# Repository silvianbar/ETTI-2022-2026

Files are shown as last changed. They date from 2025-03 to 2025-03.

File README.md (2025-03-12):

# Amplificator de Tensiune (Joasă Frecvență)
### Descriere
Acest proiect constă în proiectarea și realizarea unui amplificator de tensiune de joasă frecvență, conform specificațiilor definite. Scopul amplificatorului este de a crește amplitudinea semnalelor electrice de joasă frecvență (20 Hz - 20 kHz) menținând integritatea semnalului original.

### Specificații Tehnice

- Semnal de intrare: 360mV
- Sarcina la ieșire: 600 Ω
- Rezistența de intrare (Ri): >150 kΩ
- Rezistența de ieșire (Ro): < 0.6Ω
- Amplificare in tensiune (Av): 10
- Temperaturi de funcționare: -20°C - 120°C
- Indicator LED pentru prezența tensiunii de alimentare

### Principiul de Funcționare
Amplificatorul funcționează conform principiilor circuitelor electrice, utilizând tranzistoare pentru amplificarea semnalului. Formula fundamentală este:

`Av = Uout / Uin`

unde:

- Av este câștigul de tensiune
- Uout este tensiunea de ieșire
- Uin este tensiunea de intrare
- Pentru stabilitate, este utilizată reacția negativă, care menține amplificarea constantă.

### Componente Principale

- Etajul diferențial de intrare - folosește tranzistoare Q1 și Q2 (QBC846B)
- Sursa de curent constant - tranzistor Q5 reglează curentul circuitului
- Etajul de amplificare de tensiune - include tranzistoarele Q6, Q7 și rezistențe de stabilizare
- Etajul de ieșire - configurat push-pull cu tranzistoare Q12 și Q13 (QBC807-25)
- Indicator LED - pentru semnalizarea prezenței tensiunii de alimentare
- Schema Bloc
(Schema bloc a amplificatorului poate fi adăugată sub formă de imagine)

### Instalare și Utilizare

1. Descărcați fișierele proiectului din acest repository.
2. Construiți circuitul conform schemei electrice.
3. Alimentați circuitul cu tensiunea corespunzătoare.
4. Testați funcționarea și verificați amplificarea tensiunii de ieșire.

### Autori
Student: Baroiu Silvian
Coordonatori: Draghici Florin, Pantazica Mihaela
Licență
Acest proiect este realizat în cadrul Universității Naționale de Știință și Tehnologie Politehnica București, Facultatea de Electronică, Telecomunicații și Tehnologia Informației, 2024.

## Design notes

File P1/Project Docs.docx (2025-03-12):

Universitatea Națională de Știință și Tehnologie POLITEHNICA București Facultatea de Electronică ,Telecomunicații și Tehnologia Informației

Referat

Proiect 1 - Dispozitive și circuite electronice

Tema:

Amplificator de tensiune (joasă frecvență)

Baroiu Silvian

Grupa : 431D

Date initiale de proiectare: N = 6

Să se proiecteze și realizeze un amplificator de tensiune (joasă frecvență) având următoarele caracteristici:

- Semnal de intrare, ui in gama: 360 [mV];
- Sarcina la ieșire, RL: 60 [Ω];
- Rezistența de intrare Ri >150 [kΩ];
- Rezistența de ieșire Ro < 0,6 [Ω];
- Amplificare în tensiune, Av: 10;
- Tensiunea la ieşire 3,6 V.
- Domeniul temperaturilor de funcționare: 0-70C (verificabil prin testare în temperatură);
- Semnalizarea prezenței tensiunilor de alimentare cu diodă de tip LED.

Introducere:

Amplificatorul de tensiune este un circuit care are rolul de a furniza la iesirea sa o tensiune proportionala cu cea de la intrare. Relatia de baza este:

(1)

unde :

- Uies= este tensiunea de la iesirea amplificatorului;
- Uin= este tensiunea de la intrarea amplificatorului;
- Av= amplificarea amplificatorului , marime adimensionala , mai mare , in modul decat 1. Daca Av>0 , atunci amplificatorul se numeste neinversor , iar daca Av<0 , amplificatorul se numeste inversor.

Formula (1) este dificil de respectat cu exactitate în practică, deoarece, în special, mărimea Av nu este constantă și depinde de mai mulți factori, inclusiv de Uin. Acest lucru determină ca amplificatoarele de precizie să fie proiectate cu o reacție negativă puternică. Pentru a realiza acest lucru, se utilizează un amplificator cu două intrări: una inversoare și una neinversoare, formând astfel un amplificator diferențial. Acest tip de amplificator amplifică diferența dintre tensiunile aplicate la intrările neinversoare și inversoare.

La intrarea neinversoare se aplică semnalul, iar la cea inversoare o fracțiune din tensiunea de la ieșirea amplificatorului, cu f < 1kHz.

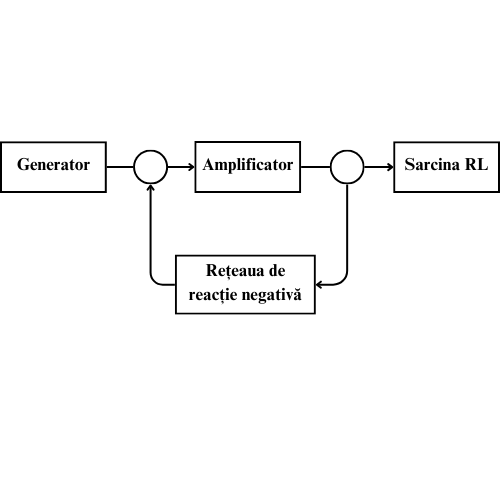
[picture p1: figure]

Schema bloc a amplificatorului de tensiune:

Schema electică a amplificatorului:

Pentru acest amplificator, am utilizat o reacție Serie-Paralel, caracterizată de o amplificare mare în buclă deschisă, o impedanță de intrare ridicată și o impedanță de ieșire foarte scăzută, fiind realizat cu ajutorul tranzistoarelor bipolare. Structura adoptată a fost următoarea:

Circuitul de intrare format din Q1 și Q2 este un amplificator diferențial realizat cu tranzistoare bipolare de joasă frecvență și putere redusă. Curentul prin cele două tranzistoare PNP este stabilit de sursa de curent Q3. Acest tranzistor furnizează un curent simetric de aproximativ 0,6 mA fiecărui tranzistor din amplificatorul diferențial.

Etajul diferențial este urmat de o oglindă de curent simetrică. Tranzistoarele Q7 și Q8, de putere redusă, sunt echipate fiecare cu o rezistență de 1 kΩ în emitor. Scopul acestei oglinzi de curent este de a asigura un curent identic la ieșire, contribuind astfel la obținerea unei liniarități ridicate și a unor distorsiuni minime.

Etajul diferențial este urmat de un amplificator în tensiune, realizat cu tranzistorul Q6, un tranzistor NPN de mică putere. Între baza și colectorul tranzistorului Q6 este conectat un condensator de compensare (efectul Miller), care are rolul de a ajusta banda de frecvență. Alimentarea tranzistorului Q6 este asigurată de tranzistorul Q7.

Etajul final funcționează în clasa B și este alcătuit din două tranzistoare care formează un tranzistor Darlington complementar. Acestea sunt compuse din perechile de tranzistoare Q10, Q11 și Q8, Q10.

Diodelor LED le este asigurată funcționarea în conducție prin intermediul unei rezistențe de 880 Ω conectată în serie. Diodelor cu joncțiune p-n li se permite de asemenea să funcționeze în regim de conducție, având următoarele valori ale curentului: diodele D1 și D2 conduc un curent de aproximativ 1,5 mA, diodele D3 și D4 circa 300 μA, iar diodele D5 și D6 aproximativ 13,4 mA.

Rețeaua de reacție negativă este formată din tranzistorul Q2 și rezistențele R9 și R10. Amplificarea în buclă închisă a montajului este dată de formula A=(R1+R2)/R1 . Pentru a respecta cerințele de proiectare, am ales raportul rezistențelor R1 și R2 să fie aproximativ 9.

Schema Electrică a Circuitului:

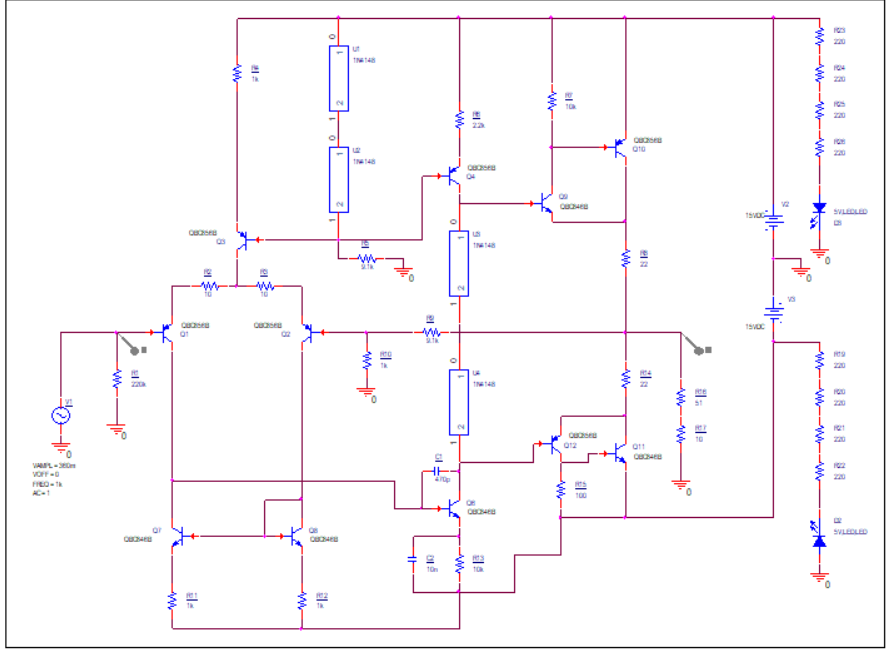
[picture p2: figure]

PSF:

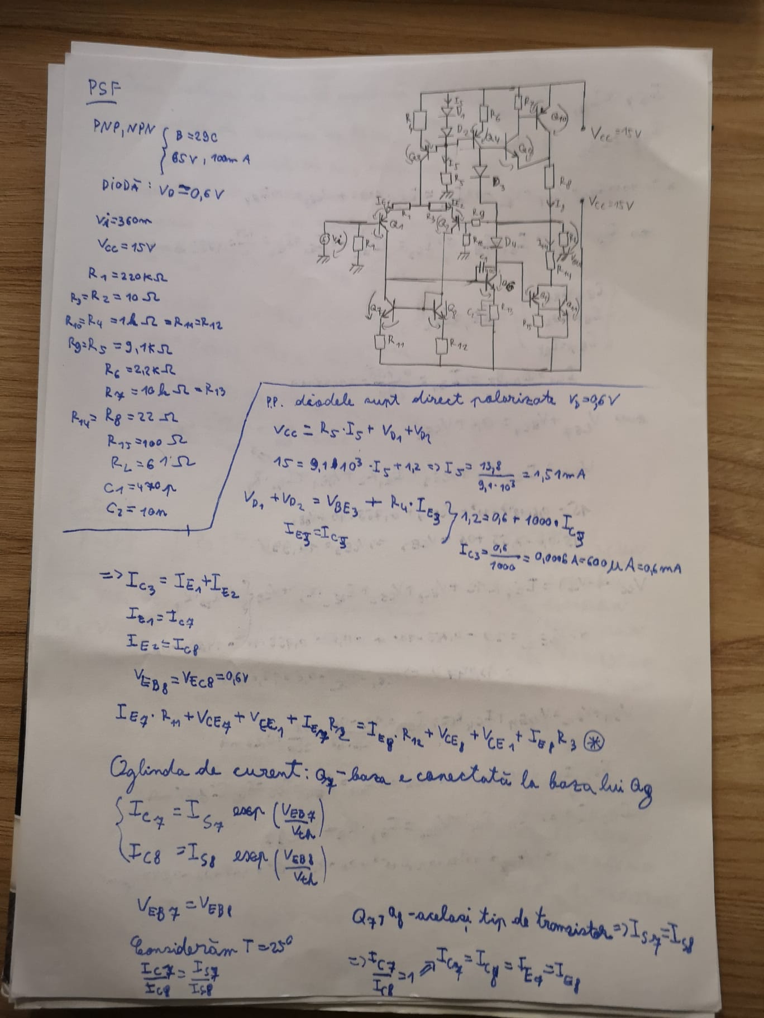
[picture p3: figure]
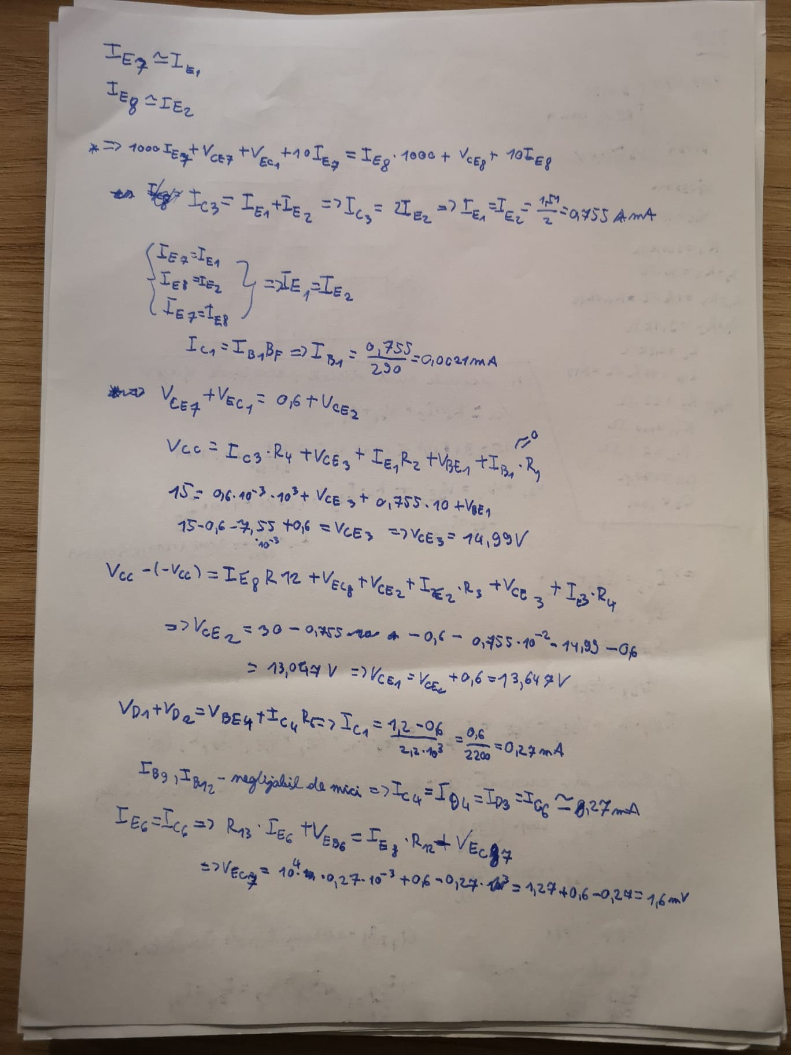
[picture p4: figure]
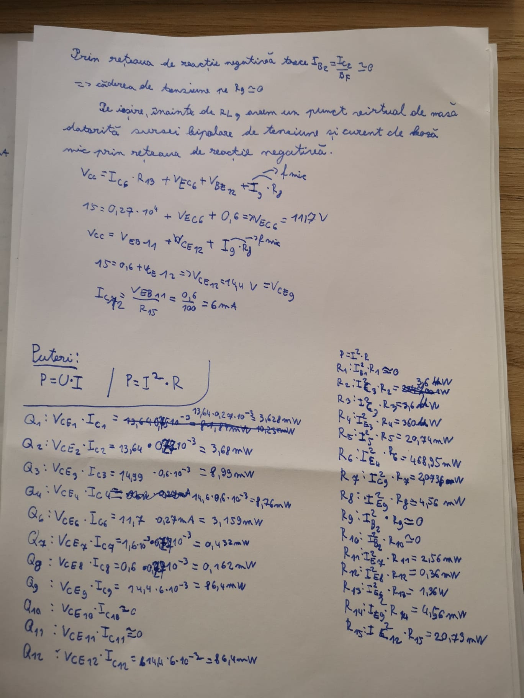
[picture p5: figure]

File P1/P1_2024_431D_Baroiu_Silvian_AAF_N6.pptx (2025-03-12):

## Circuite Electronice Fundamentale 2 – Proiect (CEF2-Pr)

Tema: Amplificator de tensiune (joasă frecvență)

Student: Baroiu Silvian
Grupa 431D

## Date de proiectare

Date initiale de proiectare: N = 6
Să se proiecteze și realizeze un amplificator de tensiune (joasă frecvență) având următoarele caracteristici:
- Semnal de intrare, ui in gama: 360 [mV];
- Sarcina la ieșire, RL: 60 [Ω];
- Rezistența de intrare Ri >150 [kΩ];
- Rezistența de ieșire Ro < 0,6 [Ω];
- Amplificare în tensiune, Av: 10;
- Tensiunea la ieşire 3,6 V.
- Domeniul temperaturilor de funcționare: 0-70C (verificabil prin testare în temperatură);
Semnalizarea prezenței tensiunilor de alimentare cu diodă de tip LED.

## Schema bloc

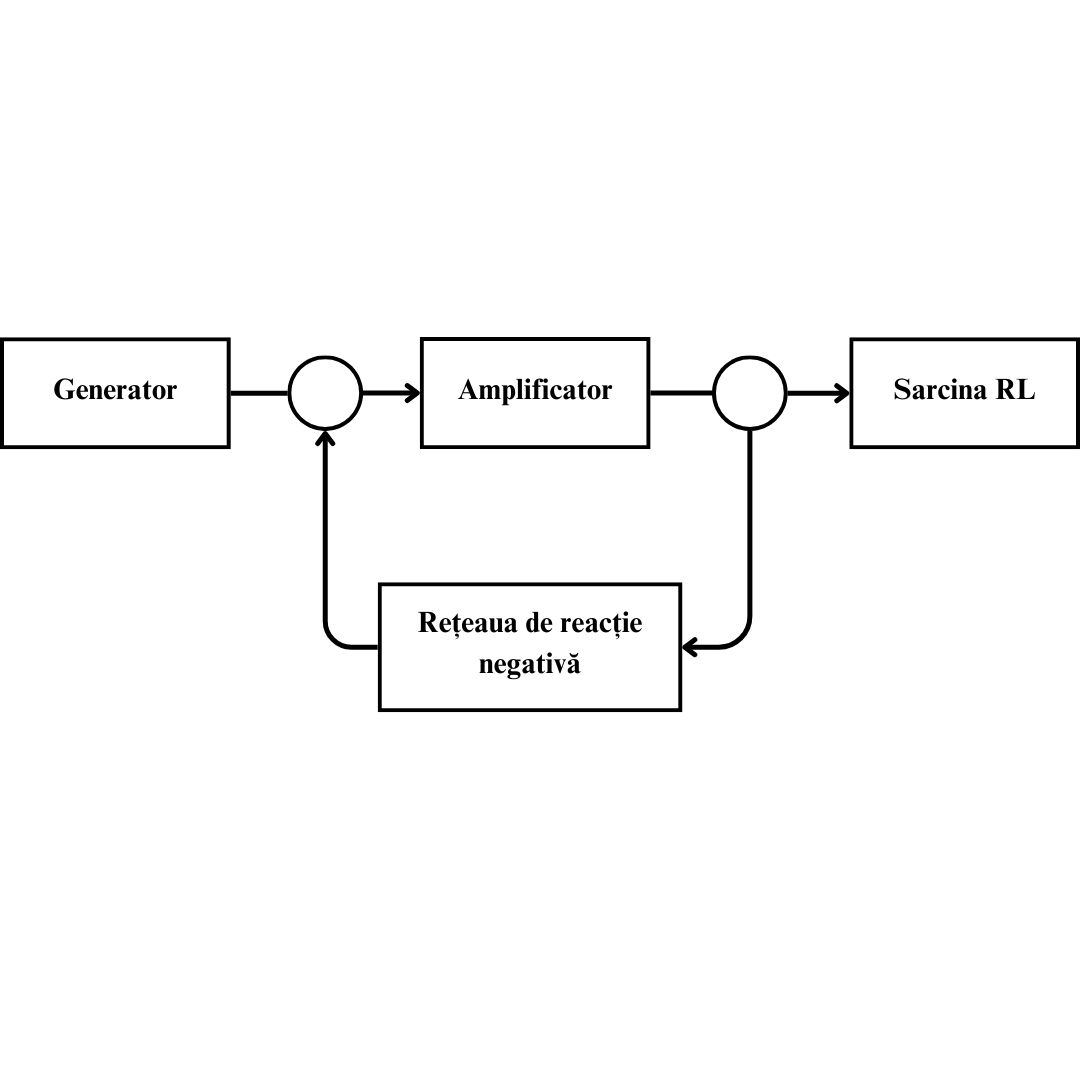
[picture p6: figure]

## Schema bloc

Schema bloc reprezintă un amplificator audio de joasă frecvență, cu o rețea de reacție negativă pentru a îmbunătăți performanțele circuitului:
- Generator: Este sursa semnalului audio de intrare care urmează să fie amplificat.
- Amplificator: Realizează amplificarea semnalului audio, crescându-i amplitudinea pentru a conduce sarcina.
- Sarcina RL: Reprezintă ieșirea care primește semnalul amplificat.
- Rețea de reacție negativă: Este utilizată pentru a prelua o parte din semnalul de ieșire și a-l reintroduce la intrarea amplificatorului cu polaritate opusă. Această reacție negativă:
1. Reduce distorsiunile semnalului.
2. Îmbunătățește stabilitatea amplificatorului.
3. Lărgește banda de frecvență a amplificatorului.
4. Reduce zgomotul și amplificarea excesivă.

## Schema electrică


## Schema electrică

Etajul de intrare (Q1 și Q2):
- Realizează amplificarea semnalului provenit de la sursa V1.
- Este configurat într-un etaj diferențial pentru a asigura un răspuns liniar, cu puțin zgomotși stabilitate ridicată.
Etajul de amplificare intermediară (Q3, Q4, și U1, U2, U3):
- Realizează amplificarea suplimentară a semnalului.
- Utilizează amplificatoare operaționale pentru stabilitate, bandă largă și performanță înaltă.
Rețea de reacție negativă:
- Este implementată prin componente rezistive și capacitive între etajele circuitului, conform principiilor evidențiate în schema bloc.
- Controlează câștigul, reduce distorsiunea

## Schema electrică

Etajul final (Q10, Q11, Q12):
- Amplifică curentul semnalului pentru a alimenta sarcina.
- Este configurat în clasă AB, pentru a echilibra eficiența energetică și distorsiunea redusă.
Stabilizarea tensiunii de alimentare (D1, D2, și V2, V3):
- Diodele Zener și sursele de tensiune oferă stabilizare.
Elemente pasive (rezistențe și condensatoare):
- Rezistențele controlează curentul prin fiecare etaj și câștigul.
- Condensatoarele elimină componentele de frecvență joasă sau înaltă nedorite, asigurând filtrarea și cuplarea corespunzătoare.

## Simulări

Dc Sweep:

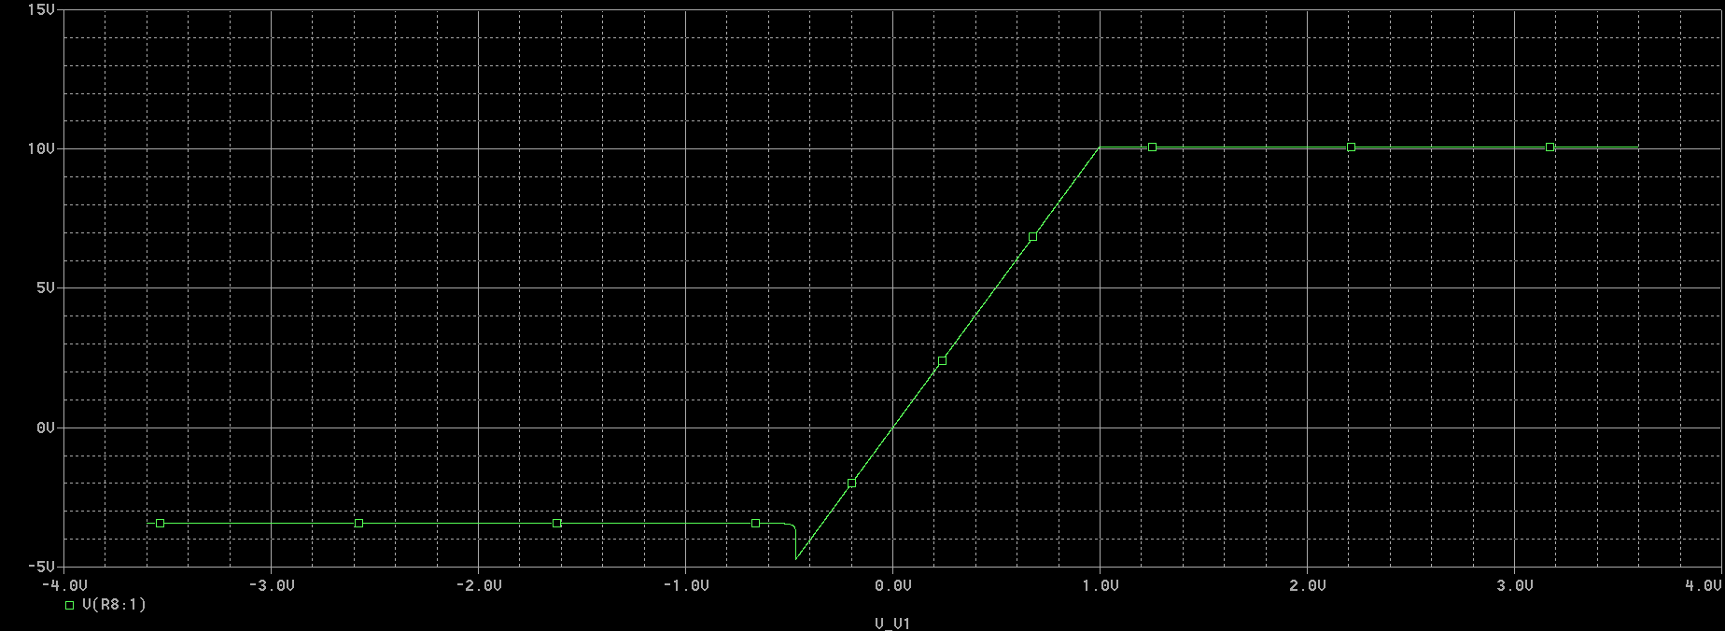
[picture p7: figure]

## Simulări

Transient+temperatura:

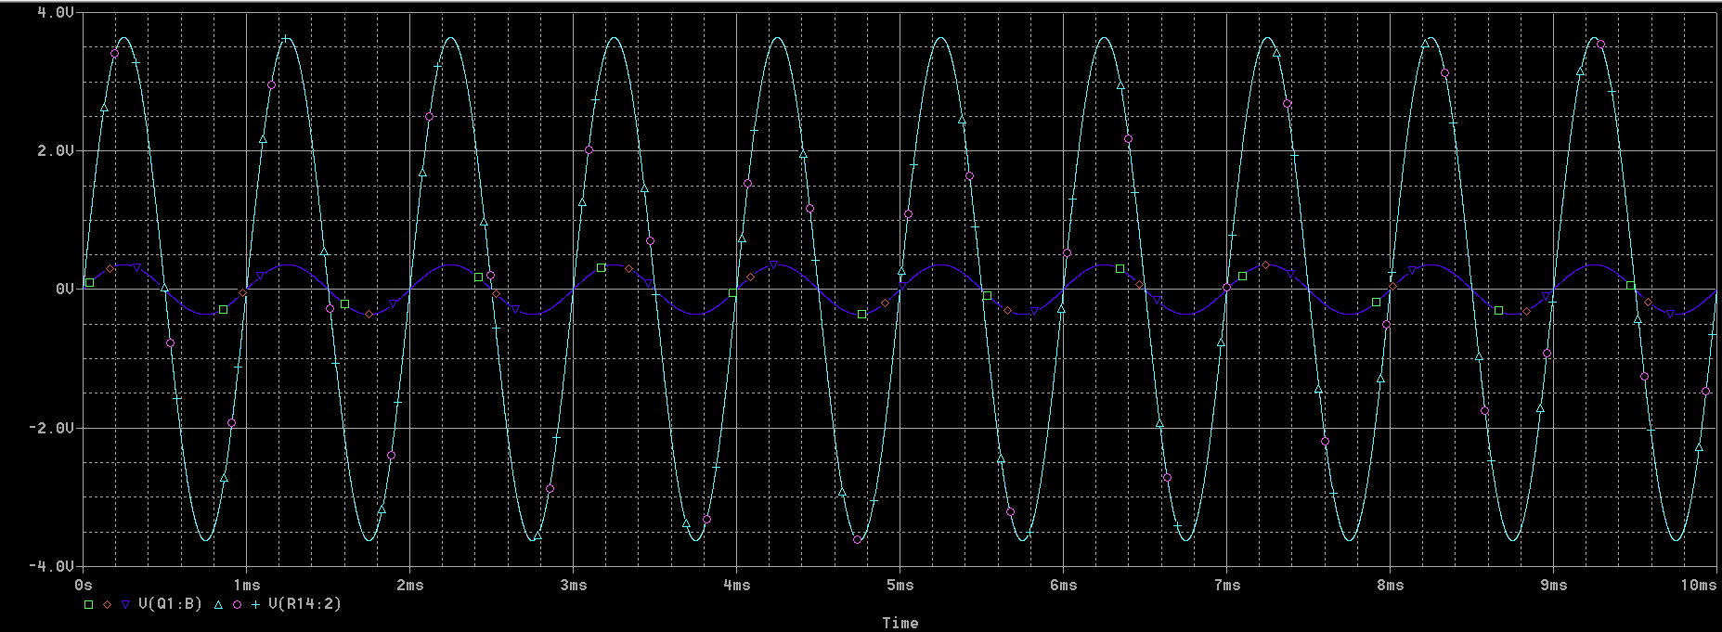
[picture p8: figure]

## Simulări

Bode:

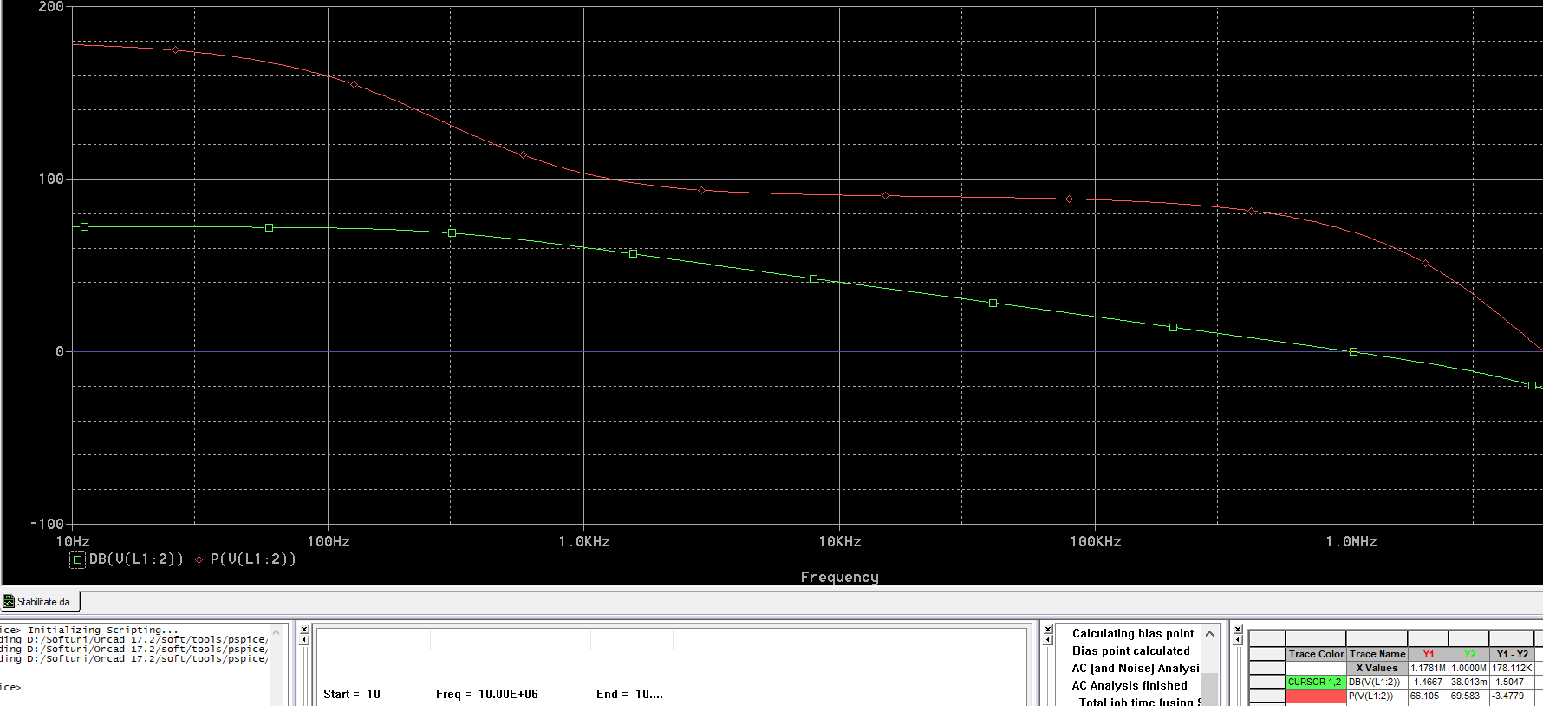
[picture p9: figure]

## Simulări

Diagrama Bode afișează două curbe: câștigul (în verde) și faza (în roșu). Stabilitatea:
Marginea de fază: Stabilitatea unui sistem de control se poate verifica analizând marginea de fază, care este diferența dintre fază și -180° în momentul în care câștigul (în decibeli) trece prin 0 dB. În diagramă, curba de fază nu scade sub -180° înainte ca câștigul să scadă sub 0 dB, ceea ce indică stabilitate.
Marginea de câștig: Este diferența în dB între câștigul real și 0 dB în momentul în care faza este -180°. Din grafic, câștigul pare să fie negativ în această zonă, ceea ce confirmă că sistemul este stabil.
Banda de frecvență
Banda de frecvență reprezintă domeniul de frecvențe în care câștigul rămâne aproape constant sau scade într-un mod previzibil. Analizând curba de câștig: Se observă că la frecvențe joase câștigul este relativ constant.
Banda de trecere se termină în jurul frecvenței unde câștigul începe să scadă rapid (de obicei, scăderea cu -3 dB față de valoarea maximă este considerată limita).

## Layout

Top Bottom

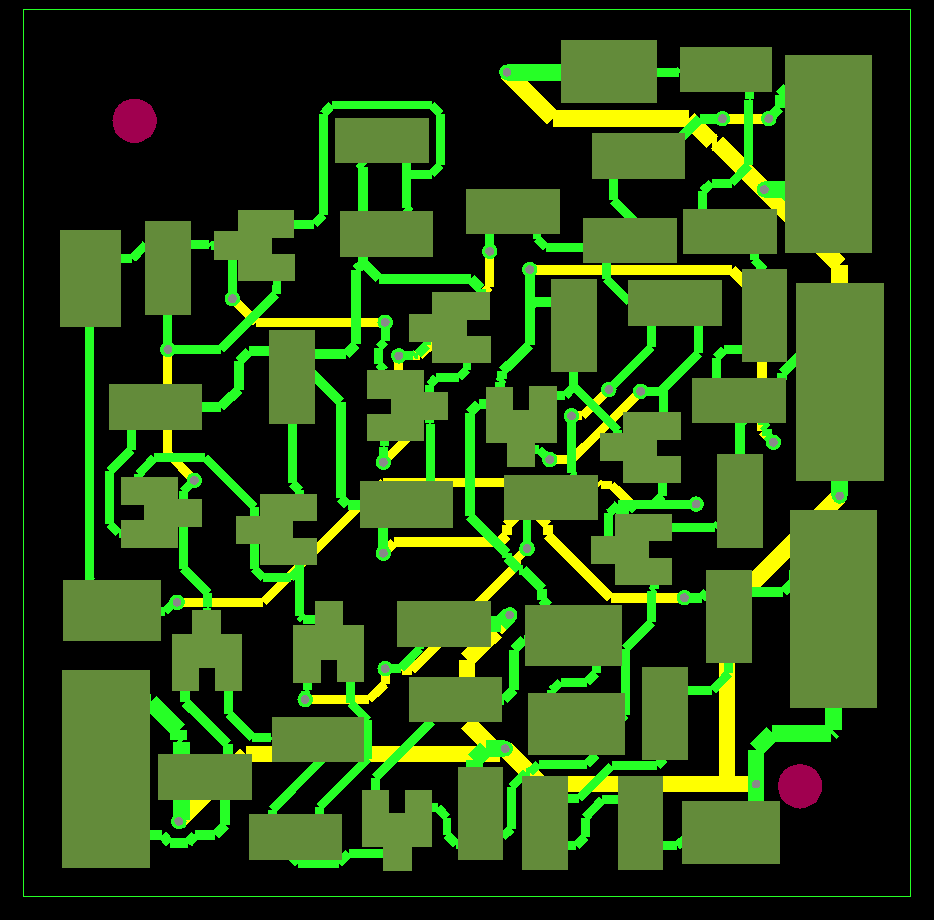
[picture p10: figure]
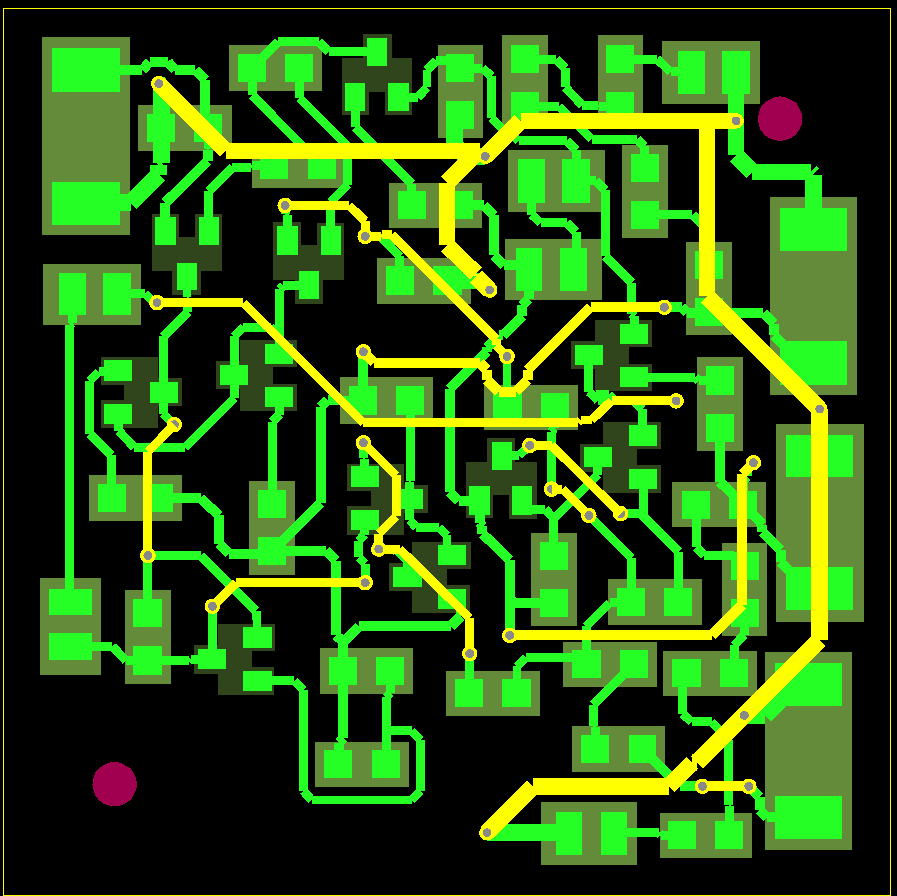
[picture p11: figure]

## Layout

- Poziționare Componente:
1. Conectorii: Au fost plasați la marginea plăcii din cauza dimensiunea acestora, ce ar crea dificultăți pentru conectarea restul componentelor.
2. Markerii Fiduciali: Au fost plasați conform cerinței.
3. Rezistențe, condensatoare, diode și tranzistoare: Au fost plasate în locuri similare cu schema electrică pentru a avea conexiuni mai simple și pentru a fi mai ușor de urmărit și găsit componentele căutate atunci când placa va fi folosită în etapa a doua.
- Dimensiuni Trasee:
Dimensiunile traseelor au fost selectate pur pe baza cerințelor temei primite.

## Fotografii din etapa de echipare a modulului electronic

- Layout PCB
- Foto PCB echipat
- Maxim o pagină

- se va completa în Sem. al II-lea

## Rezultate experimentale

- Foto forme de undă
- Tabele măsurători
- Tot ceea ce justifică funcționarea proiectului în specificațiile impuse
- Maxim două pagini

- se va completa în Sem. al II-lea

## Rezultate experimentale

- Tabel comparativ

Cerințe impuse | Rezultate simulări | Rezultate măsurători
Semnal de intrare, ui in gama: 360 [mV]; | 360 [mV]
Sarcina la ieșire, RL: 60 [Ω]; | 60 [Ω]
Rezistența de intrare Ri >150 [kΩ]; | 219 [kΩ]
Rezistență ieșire Ro < 0,6 [Ω] | 0.54 [Ω]
Amplificare, Av: 10; | 10
Tensiunea la ieşire 3,6 V. | 3.6 V
Domeniul temperaturilor: 0-70C | Bun

- se va completa în Sem. al II-lea

## Concluzii

- Se comentează rezultatele obținute
- Ce îmbunătățiri ar putea fi aduse
- În cazul în care proiectul nu a funcționat la prima încercare, se scot în evidență erorile de concept/realizare (d.p.d.v al proiectării schemei, layout-ului, etc. )
- Cum ar putea fi depanat – plan de depanare (organigramă)
- Maxim două pagini
- ! Timpul maxim acordat expunerii este de 5-6 minute

- se va completa în Sem. al II-lea

## Concluzii

- Ce cunoștințe au fost dobândite pe parcursul activităților desfășurate în cadrul proiectului
- Evidențiați, dacă există, părțile bune legate de activitatea depusă și/ sau precizați părțile slabe existente în organizarea desfășurării proiectului
- Care ar fi propunerea voastră, privind modul în care ar trebui să se desfășoare activitățile cerute de proiect, pentru a se asigura finalizarea sa. Prezentați diagrama Gantt corespunzătoare.
- Maxim două pagini
- ! Timpul maxim acordat expunerii este de 5-6 minute

- se va completa în Sem. al II-lea

## Discipline studiate utile în realizarea proiectului

- Se trec disciplinele din care au fost utilizate cunoștințe/informații pentru realizarea proiectului
- Ce discipline, aflate în semestrele din amonte, ar fi trebuit să fie mai bine însușite pentru ușurarea realizării activităților conexe proiectului?

- se va completa în Sem. al II-lea

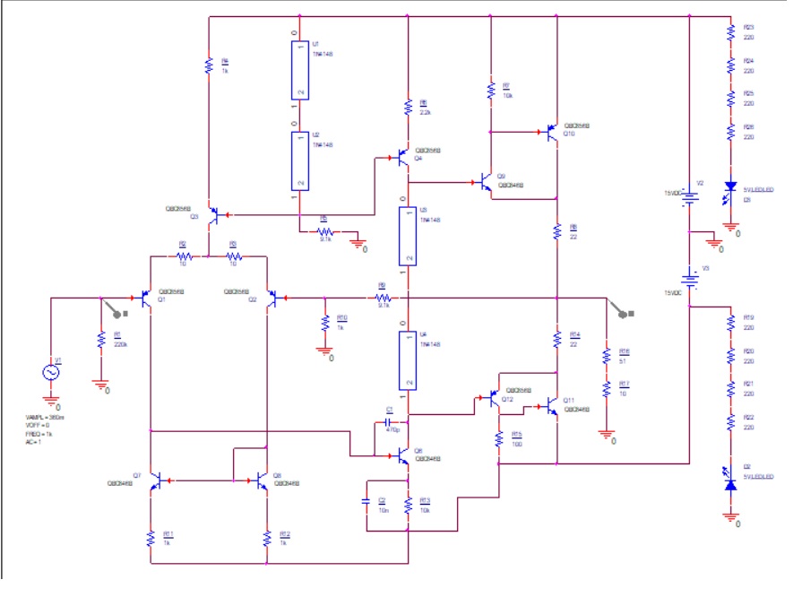
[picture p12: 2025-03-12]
P1/Schematics/Schema.jpg

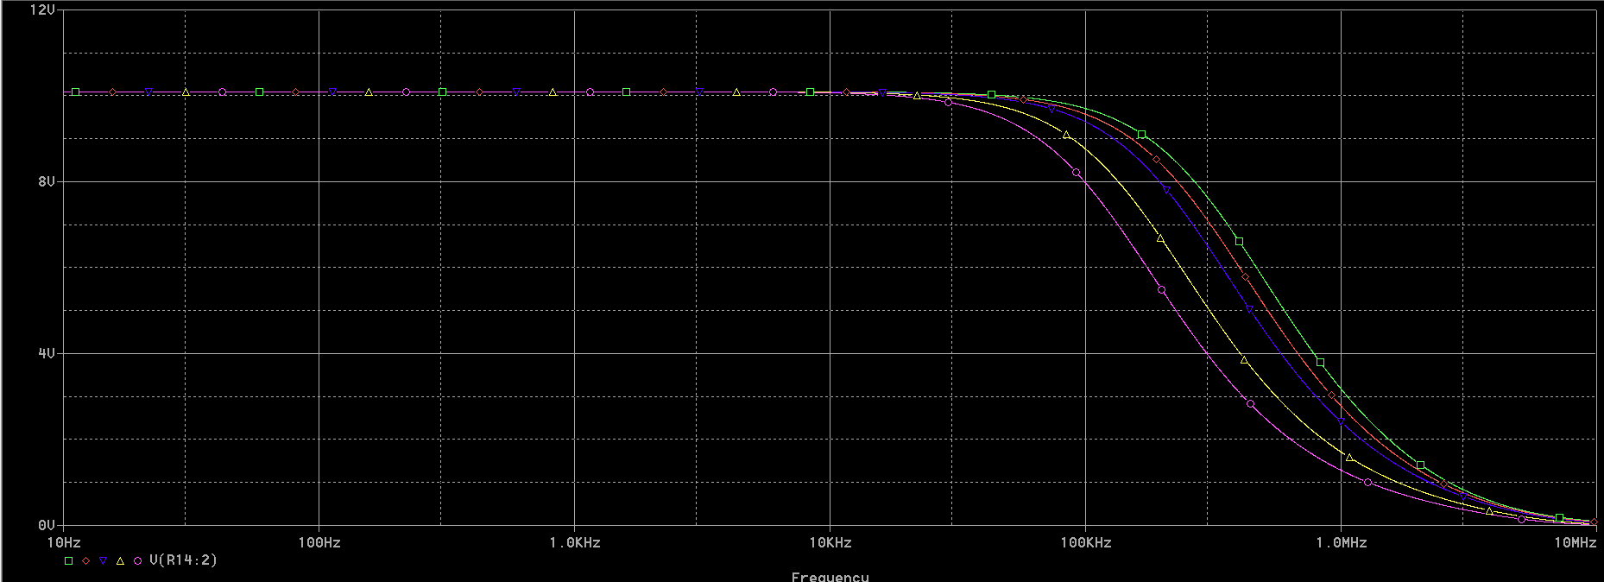
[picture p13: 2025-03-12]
P1/Simulations/Temperatura_AC.png

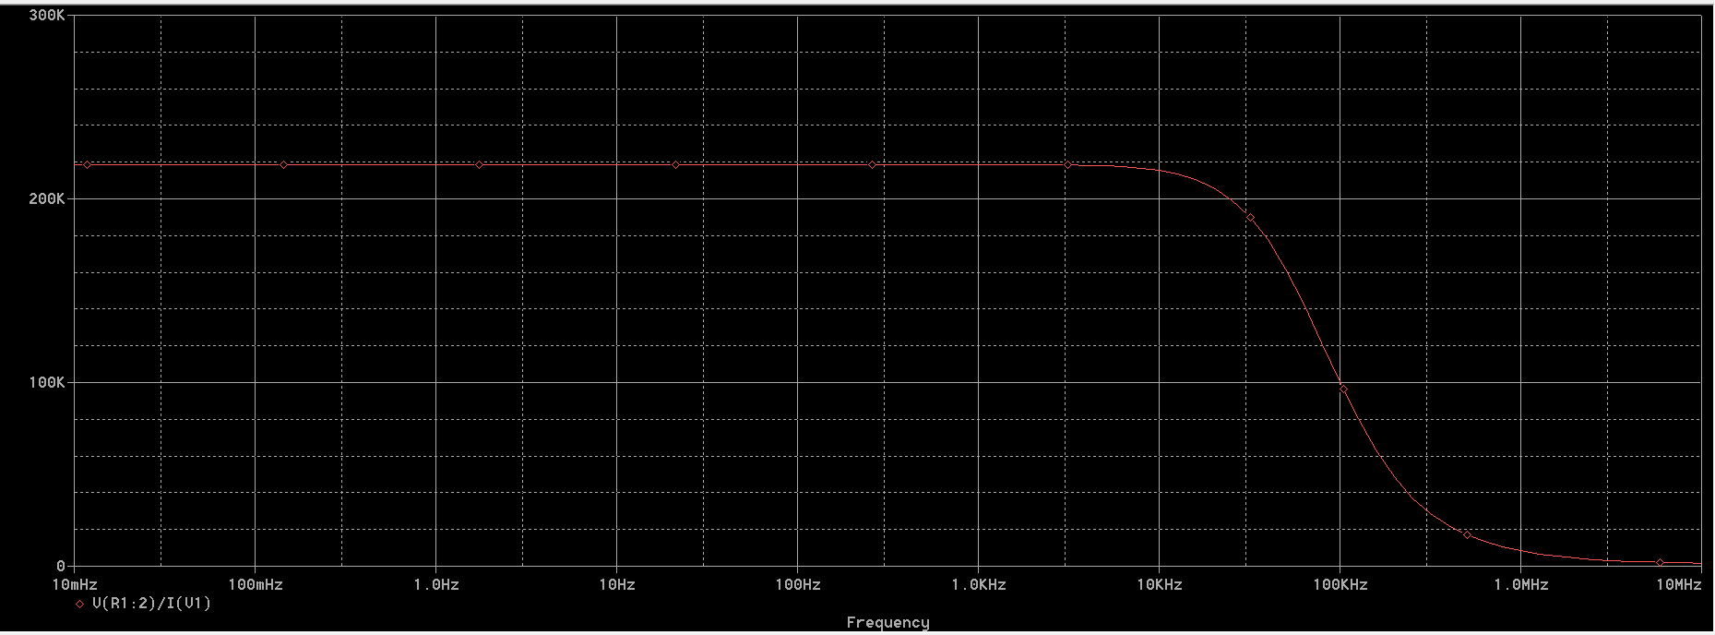
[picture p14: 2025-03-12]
P1/Simulations/Rezistenta_la_intrare.png

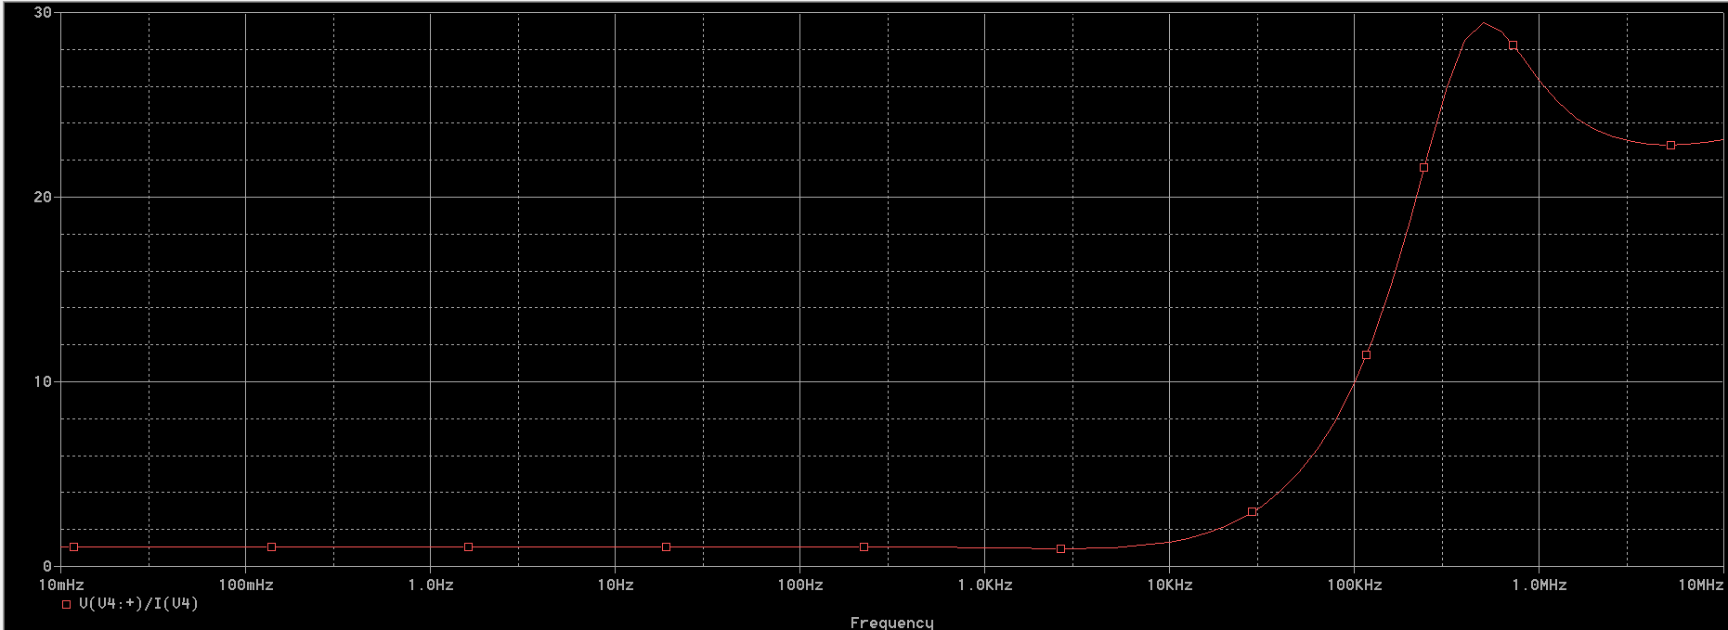
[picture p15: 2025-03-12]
P1/Simulations/Rezistenta_la_iesire.png

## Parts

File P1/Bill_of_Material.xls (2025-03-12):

Anexa a1 - Grupa 433E - Tema 2 - Amplificator de tensiune (joasă frecvență)
Nr. Crt. | Nume | Catalog | Cod distrib | Nume prod | Prod | Clasă | Qty fix | Qty final | Qty min | Descriere | Distribuitor | Pret (fara TVA) referinta/buc. TME România | Pret total pe reper (fara TVA) - propus
1 | 0 ohm | (LINK) (http://www.tme.eu/ro/details/smd1206-0r/rezistente-smd-1206/royal-ohm/1206s4j0000t5e/) | 1206S4J0000T5E | 1206S4J0000T5E | SR PASSIVES | rezistor | 0 |  | 0 | Rezistor: thick film; SMD; 1206; 0Ω; 0,25W; ±5%; -55÷125°C | TME România | 0.03841 | 0
2 | 0.47 | (LINK) (http://www.tme.eu/ro/details/smd0805-0r47/rezistente-smd-0805/royal-ohm/0805s8j047kt5e/) | SMD0805-0R47 | 0805S8J047KT5E | ROYAL OHM | rezistor | 30 |  | 0 | Rezistor SMD, chip, 0805, 0.47Ω, ±5%, 0.125W | TME România | 0.01454 | 0.4362
3 | 1 | (LINK) (https://www.tme.eu/ro/details/smd0805-1r/rezistente-smd-0805/royal-ohm/0805s8j010jt5e/) | SMD0805-1R-5% | 0805S8J010JT5E | ROYAL OHM | rezistor | 30 |  | 0 | Rezistor SMD, chip, 0805, 1Ω, ±5%, 0.125W | TME România | 0.01723 | 0.5169
4 | 4.7 | (LINK) (https://www.tme.eu/ro/details/smd0805-4r7/rezistente-smd-0805/royal-ohm/0805s8j047jt5e/) | SMD0805-4R7-5% | 0805S8J047JT5E | ROYAL OHM | rezistor | 10 |  | 0 | Rezistor SMD, chip, 0805, 4.7Ω, ±5%, 0.125W | TME România | 0.01723 | 0.1723
5 | 10 | (LINK) (https://www.tme.eu/ro/details/smd0805-10r/rezistente-smd-0805/royal-ohm/0805s8j0100t5e/) | SMD0805-10R-5% | 0805S8J0100T5E | ROYAL OHM | rezistor | 10 |  | 3 | Rezistor SMD, chip, 0805, 10Ω, ±5%, 0.125W | TME România | 0.01723 | 0.1723
6 | 22 | (LINK) (https://www.tme.eu/ro/details/smd0805-22r-1%25/rezistente-smd-0805/royal-ohm/0805s8f220jt5e/) | SMD0805-22R-1% | 0805S8F220JT5E | ROYAL OHM | rezistor | 20 |  | 2 | Rezistor SMD, chip, 0805, 22Ω, ±1%, 0.125W | TME România | 0.02127 | 0.4254
7 | 33 | (LINK) (https://www.tme.eu/ro/details/smd0805-33r/rezistente-smd-0805/royal-ohm/0805s8j0330t5e/) | SMD0805-33R-5% | 0805S8J0330T5E | ROYAL OHM | rezistor | 20 |  | 0 | Rezistor SMD, chip, 0805, 33Ω, ±5%, 0.125W | TME România | 0.01723 | 0.3446
8 | 51 | (LINK) (http://www.tme.eu/ro/details/rc0805jr-0751r/rezistente-smd-0805/yageo/rc0805jr-0751rl/) | SMD0805-51R-5% | 0805S8J0510T5E | ROYAL OHM | rezistor | 40 |  | 1 | Rezistor SMD, chip, 0805, 51Ω, ±5%, 0.125W | TME România | 0.0261 | 1.044
9 | 68 | (LINK) (http://www.tme.eu/ro/details/smd0805-68r-1%25/rezistente-smd-0805/royal-ohm/0805s8f680jt5e/) | SMD0805-68R-1% | 0805S8F680JT5E | ROYAL OHM | rezistor | 10 |  | 0 | Rezistor SMD, chip, 0805, 68Ω, ±1%, 0.125W | TME România | 0.04662 | 0.4662
10 | 82 | (LINK) (https://www.tme.eu/ro/details/wf08p-82r-5%25/rezistente-smd-0805/walsin/wf08p820jtl/) | SMD0805-82R-5% | WF08P820JTL | WALSIN | rezistor | 20 |  | 0 | Rezistor SMD, chip, 0805, 82Ω, ±5%, 0.125W | TME România | 0.0172 | 0.344
11 | 100 | (LINK) (https://www.tme.eu/ro/details/smd0805-100r/rezistente-smd-0805/royal-ohm/0805s8j0101t5e/) | SMD0805-100R-5% | 0805S8J0101T5E | ROYAL OHM | rezistor | 60 |  | 1 | Rezistor SMD, chip, 0805, 100Ω, ±5%, 0.125W | TME România | 0.01723 | 1.0338
12 | 150 | (LINK) (https://www.tme.eu/ro/details/smd0805-150r/rezistente-smd-0805/royal-ohm/0805s8j0151t5e/) | SMD0805-150R-5% | 0805S8F1500T5E | ROYAL OHM | rezistor | 20 |  | 0 | Rezistor SMD, chip, 0805, 150Ω, ±5%, 0.125W | TME România | 0.01723 | 0.3446
13 | 220 | (LINK) (http://www.tme.eu/ro/details/smd0805-220r-1%25/rezistente-smd-0805/royal-ohm/0805s8f2200t5e/) | SMD0805-220R-5% | 0805S8J0221T5E | ROYAL OHM | rezistor | 20 |  | 8 | Rezistor SMD, chip, 0805, 220Ω, ±5%, 0.125W | TME România | 0.02127 | 0.4254
14 | 330 | (LINK) (https://www.tme.eu/ro/details/smd0805-330r/rezistente-smd-0805/royal-ohm/0805s8j0331t5e/) | SMD0805-330R-5% | 0805S8J0331T5E | ROYAL OHM | rezistor | 20 |  | 0 | Rezistor SMD, chip, 0805, 330Ω, ±5%, 0.125W | TME România | 0.01723 | 0.3446
15 | 470 | (LINK) (https://www.tme.eu/ro/details/smd0805-470r/rezistente-smd-0805/royal-ohm/0805s8j0471t5e/) | SMD0805-470R-5% | 0805S8J0471T5E | ROYAL OHM | rezistor | 20 |  | 0 | Rezistor SMD, chip, 0805, 470Ω, ±5%, 0.125W | TME România | 0.01723 | 0.3446
16 | 510 | (LINK) (https://www.tme.eu/ro/details/smd0805-510r/rezistente-smd-0805/royal-ohm/0805s8j0511t5e/) | SMD0805-510R-5% | 0805S8J0511T5E | YAGEO | rezistor | 30 |  | 0 | Rezistor SMD, chip, 0805, 510Ω, ±5%, 0.125W | TME România | 0.01723 | 0.5169
17 | 680 | (LINK) (https://www.tme.eu/ro/details/smd0805-680r/rezistente-smd-0805/royal-ohm/0805s8j0681t5e/) | SMD0805-680R-5% | 0805S8J0681T5E | ROYAL OHM | rezistor | 30 |  | 0 | Rezistor SMD, chip, 0805, 680Ω, ±5%, 0.125W | TME România | 0.01723 | 0.5169
18 | 820 | (LINK) (https://www.tme.eu/ro/details/smd0805-820r/rezistente-smd-0805/royal-ohm/0805s8j0821t5e/) | SMD0805-820R-5% | 0805S8J0821T5E | ROYAL OHM | rezistor | 20 |  | 0 | Rezistor SMD, chip, 0805, 820Ω, ±5%, 0.125W | TME România | 0.01723 | 0.3446
19 | 910 | (LINK) (https://www.tme.eu/ro/details/rc0805jr-07910r/rezistente-smd-0805/yageo/rc0805jr-07910rl/) | SMD0805-910R-5% | RC0805JR-07910RL | YAGEO | rezistor | 20 |  | 0 | Rezistor SMD, chip, 0805, 910Ω, ±5%, 0.125W | TME România | 0.0261 | 0.522
20 | 1k | (LINK) (https://www.tme.eu/ro/details/smd0805-1k/rezistente-smd-0805/royal-ohm/0805s8j0102t5e/) | SMD0805-1K-5% | 0805S8J0102T5E | ROYAL OHM | rezistor | 100 |  | 4 | Rezistor SMD, chip, 0805, 1kΩ, ±5%, 0.125W | TME România | 0.01723 | 1.723
21 | 1.5k | (LINK) (https://www.tme.eu/ro/details/wf08p-1k5-5%25/rezistente-smd-0805/walsin/wf08p152jtl/) | SMD0805-1K5-5% | WF08P152JTL | WALSIN | rezistor | 20 |  | 0 | Rezistor SMD, chip, 0805, 1.5kΩ, ±5%, 0.125W | TME România | 0.0172 | 0.344
22 | 1.8k | (LINK) (https://www.tme.eu/ro/details/smd0805-1k8/rezistente-smd-0805/royal-ohm/0805s8j0182t5e/) | SMD0805-1K8-5% | 0805S8J0182T5E | ROYAL OHM | rezistor | 20 |  | 0 | Rezistor SMD, chip, 0805, 1.8kΩ, ±5%, 0.125W | TME România | 0.01723 | 0.3446
23 | 2k | (LINK) (https://www.tme.eu/ro/details/smd0805-2k/rezistente-smd-0805/royal-ohm/0805s8j0202t5e/) | SMD0805-2K-5% | 0805S8J0202T5E | ROYAL OHM | rezistor | 80 |  | 0 | Rezistor SMD, chip, 0805, 2kΩ, ±5%, 0.125W | TME România | 0.01723 | 1.3784
24 | 2.2k | (LINK) (https://www.tme.eu/ro/details/smd0805-2k2/rezistente-smd-0805/royal-ohm/0805s8j0222t5e/) | SMD0805-2K2-5% | 0805S8J0222T5E | ROYAL OHM | rezistor | 20 |  | 1 | Rezistor SMD, chip, 0805, 2.2kΩ, ±5%, 0.125W | TME România | 0.01723 | 0.3446
25 | 2.7k | (LINK) (https://www.tme.eu/ro/details/smd0805-2k7/rezistente-smd-0805/royal-ohm/0805s8j0272t5e/) | SMD0805-2K7-5% | 0805S8F2701T5E | ROYAL OHM | rezistor | 20 |  | 0 | Rezistor SMD, chip, 0805, 2.7kΩ, ±5%, 0.125W | TME România | 0.01723 | 0.3446
26 | 3.3k | (LINK) (https://www.tme.eu/ro/details/smd0805-3k3/rezistente-smd-0805/royal-ohm/0805s8j0332t5e/) | SMD0805-3K3-5% | 0805S8J0332T5E | ROYAL OHM | rezistor | 30 |  | 0 | Rezistor SMD, chip, 0805, 3.3kΩ, ±5%, 0.125W | TME România | 0.01723 | 0.5169
27 | 3.9k | (LINK) (https://www.tme.eu/ro/details/smd0805-3k9/rezistente-smd-0805/royal-ohm/0805s8j0392t5e/) | SMD0805-3K9-5% | 0805S8J0392T5E | ROYAL OHM | rezistor | 20 |  | 0 | Rezistor SMD, chip, 0805, 3.9kΩ, ±5%, 0.125W | TME România | 0.01723 | 0.3446
28 | 4.7k | (LINK) (https://www.tme.eu/ro/details/smd0805-4k7/rezistente-smd-0805/royal-ohm/0805s8j0472t5e/) | SMD0805-4K7-5% | 0805S8J0472T5E | ROYAL OHM | rezistor | 30 |  | 0 | Rezistor SMD, chip, 0805, 4.7kΩ, ±5%, 0.125W | TME România | 0.01723 | 0.5169
29 | 5.6k | (LINK) (https://www.tme.eu/ro/details/smd0805-5k6/rezistente-smd-0805/royal-ohm/0805s8j0562t5e/) | SMD0805-5K6-5% | 0805S8J0562T5E | ROYAL OHM | rezistor | 40 |  | 0 | Rezistor SMD, chip, 0805, 5.6kΩ, ±5%, 0.125W | TME România | 0.01723 | 0.6892
30 | 6.8k | (LINK) (https://www.tme.eu/ro/details/rc0805jr-076k8/rezistente-smd-0805/yageo/rc0805jr-076k8l/) | SMD0805-6K8-5% | RC0805JR-076K8L | YAGEO | rezistor | 20 |  | 0 | Rezistor SMD, chip, 0805, 6.8kΩ, ±5%, 0.125W | TME România | 0.0261 | 0.522
31 | 8.2k | (LINK) (https://www.tme.eu/ro/details/smd0805-8k2/rezistente-smd-0805/royal-ohm/0805s8j0822t5e/) | SMD0805-8K2-5% | 0805S8J0822T5E | ROYAL OHM | rezistor | 30 |  | 0 | Rezistor SMD, chip, 0805, 8.2kΩ, ±5%, 0.125W | TME România | 0.01723 | 0.5169
32 | 9.1k | (LINK) (https://www.tme.eu/ro/details/smd0805-9k1/rezistente-smd-0805/royal-ohm/0805s8j0912t5e/) | SMD0805-9K1-5% | 0805S8J0912T5E | ROYAL OHM | rezistor | 20 |  | 2 | Rezistor SMD, chip, 0805, 9.1kΩ, ±5%, 0.125W | TME România | 0.01723 | 0.3446
33 | 10k | (LINK) (https://www.tme.eu/ro/details/smd0805-10k/rezistente-smd-0805/royal-ohm/0805s8j0103t5e/) | SMD0805-10K-5% | 0805S8J0103T5E | ROYAL OHM | rezistor | 100 |  | 2 | Rezistor SMD, chip, 0805, 10kΩ, ±5%, 0.125W | TME România | 0.01723 | 1.723
34 | 15k | (LINK) (https://www.tme.eu/ro/details/smd0805-15k/rezistente-smd-0805/royal-ohm/0805s8j0153t5e/) | SMD0805-15K-5% | 0805S8J0153T5E | ROYAL OHM | rezistor | 30 |  | 0 | Rezistor SMD, chip, 0805, 15kΩ, ±5%, 0.125W | TME România | 0.01723 | 0.5169
35 | 22k | (LINK) (https://www.tme.eu/ro/details/smd0805-22k/rezistente-smd-0805/royal-ohm/0805s8j0223t5e/) | SMD0805-22K-5% | 0805S8J0223T5E | ROYAL OHM | rezistor | 30 |  | 0 | Rezistor SMD, chip, 0805, 22kΩ, ±5%, 0.125W | TME România | 0.01723 | 0.5169
36 | 47k | (LINK) (http://www.tme.eu/ro/details/smd0805-47k/rezistente-smd-0805/royal-ohm/0805s8j0473t5e/) | SMD0805-47K-5% | 0805S8J0473T5E | ROYAL OHM | rezistor | 40 |  | 0 | Rezistor: thick film; SMD; 0805; 47kΩ; 0,125W; ±5%; -55÷125°C | TME România | 0.01723 | 0.6892
37 | 68k | (LINK) (https://www.tme.eu/ro/details/smd0805-68k/rezistente-smd-0805/royal-ohm/0805s8j0683t5e/) | SMD0805-68K-5% | 0805S8J0683T5E | ROYAL OHM | rezistor | 20 |  | 0 | Rezistor SMD, chip, 0805, 68kΩ, ±5%, 0.125W | TME România | 0.01723 | 0.3446
38 | 100k | (LINK) (https://www.tme.eu/ro/details/smd0805-100k/rezistente-smd-0805/royal-ohm/0805s8j0104t5e/) | SMD0805-100K-5% | 0805S8J0104T5E | ROYAL OHM | rezistor | 100 |  | 0 | Rezistor SMD, chip, 0805, 100kΩ, ±5%, 0.125W | TME România | 0.01723 | 1.723
39 | 150k | (LINK) (http://www.tme.eu/ro/details/smd0805-150k/rezistente-smd-0805/royal-ohm/0805s8j0154t5e/) | SMD0805-150K-5% | 0805S8J0154T5E | ROYAL OHM | rezistor | 30 |  | 0 | Rezistor SMD, chip, 0805, 150kΩ, ±5%, 0.125W | TME România | 0.01723 | 0.5169
40 | 180k | (LINK) (http://www.tme.eu/ro/details/smd0805-180k/rezistente-smd-0805/royal-ohm/0805s8j0184t5e/) | SMD0805-180K-5% | 0805S8J0184T5E | ROYAL OHM | rezistor | 30 |  | 0 | Rezistor SMD, chip, 0805, 180kΩ, ±5%, 0.125W | TME România | 0.01723 | 0.5169
41 | 220k | (LINK) (https://www.tme.eu/ro/details/smd0805-220k/rezistente-smd-0805/royal-ohm/0805s8j0224t5e/) | SMD0805-220K-5% | 0805S8J0224T5E | ROYAL OHM | rezistor | 30 |  | 1 | Rezistor SMD, chip, 0805, 220kΩ, ±5%, 0.125W | TME România | 0.01723 | 0.5169
42 | 330k | (LINK) (https://www.tme.eu/ro/details/smd0805-330k/rezistente-smd-0805/royal-ohm/0805s8j0334t5e/) | SMD0805-330K-5% | 0805S8J0334T5E | ROYAL OHM | rezistor | 30 |  | 0 | Rezistor SMD, chip, 0805, 330kΩ, ±5%, 0.125W | TME România | 0.01723 | 0.5169
43 | 390k | (LINK) | SMD0805-390K-5% | 0805S8J0394T5E | ROYAL OHM | rezistor | 30 |  | 0 | Rezistor SMD, chip, 0805, 390kΩ, ±5%, 0.125W | TME România | 0.01723 | 0.5169
44 | 510k | (LINK) (https://www.tme.eu/ro/details/smd0805-510k/rezistente-smd-0805/royal-ohm/0805s8j0514t5e/) | SMD0805-510K-5% | 0805S8J0514T5E | ROYAL OHM | rezistor | 30 |  | 0 | Rezistor SMD, chip, 0805, 510kΩ, ±5%, 0.125W | TME România | 0.01723 | 0.5169
45 | 1M | (LINK) (https://www.tme.eu/ro/details/crcw08051m00jntabc/rezistente-smd-0805/vishay/) | SMD0805-1M-5% | CRCW08051M00JNTABC | VISHAY | rezistor | 30 |  | 0 | Rezistor SMD, chip, 0805, 1MΩ, ±5%, 0.125W | TME România | 0.01151 | 0.3453
46 | 2M | (LINK) (http://www.tme.eu/ro/details/smd0805-2m/rezistente-smd-0805/royal-ohm/0805waj-2m-t5e/) | SMD0805-2M7 5% | 0805WAJ 2M T5E | ROYAL OHM | rezistor | 30 |  | 0 | Rezistor SMD, chip, 0805, 2MΩ, ±1%, 0.125W | TME România | 0.01723 | 0.5169
47 | 5,1M | (LINK) (http://www.tme.eu/ro/details/smd0805-5m1/rezistente-smd-0805/royal-ohm/0805s8j0515t5e/) | SMD0805-5M1 5% | RC0805FR-075M1 | Yageo | rezistor | 30 |  | 0 | Rezistor SMD, chip, 0805, 5.1MΩ, ±1%, 0.125W | TME România | 0.01723 | 0.5169
48 | 10M | (LINK) (https://www.tme.eu/ro/details/0805s8j0106t5e/rezistente-smd-0805/royal-ohm/) | SMD0805-10M 5% | 0805S8J0106T5E | ROYAL OHM | rezistor | 20 |  | 0 | Rezistor SMD, chip, 0805, 10MΩ, ±5%, 0.125W | TME România | 0.01723 | 0.3446
49 | 100ohm | (LINK) (https://www.tme.eu/ro/details/ts53yl100r/trimere-smd-cu-o-singura-tura/vishay/ts53yl101mr10/) | 1804GSMD-100R | 1804GSMD-100R | SR PASSIVES | potențiometru | 20 |  | 0 | Potențiome-tru liniar, simplă tură, SMD, 100Ω, ±10%, 100ppm/°C, 0.25W | TME România | 3.77 | 75.4
50 | 500ohm | (LINK) (https://www.tme.eu/ro/details/ts53yl500r/trimere-smd-cu-o-singura-tura/vishay/ts53yl501mr10/) | 1804GSMD-500R | 1804GSMD-500R | VISHAY | potențiometru | 10 |  | 0 | Potențiome-tru liniar, simplă tură, SMD, 500Ω, ±10%, 100ppm/°C, 0.25W | TME România | 2.19 | 21.9
51 | 2k | (LINK) (https://www.tme.eu/ro/details/ts53yl2k/trimere-smd-cu-o-singura-tura/vishay/ts53yl202mr10/) | TS53YL202MR10 | TS53YL202MR10 | VISHAY | potențiometru | 50 |  | 0 | Potențiome-tru liniar, simplă tură, SMD, 2kΩ, ±20%, 100ppm/°C, 0.25W | TME România | 2.84 | 142
52 | 5k | (LINK) (http://www.tme.eu/ro/details/3314g-1-502e/trimere-smd-cu-o-singura-tura/bourns/) | 3314G-1-502E | 3314G-1-502E | BOURNS | potențiometru | 0 |  | 0 | Potențiome-tru liniar, simplă tură, SMD, 5kΩ, ±20%, 100ppm/°C, 0.25W | TME România | 3.45 | 0
53 | 10k | (LINK) (http://www.tme.eu/ro/details/3314g-1-103e/trimere-smd-cu-o-singura-tura/bourns/) | 3314G-1-103E | 3314G-1-103E | BOURNS | potențiometru | 0 |  | 0 | Potențiome-tru liniar, simplă tură, SMD, 10kΩ, ±20%, 100ppm/°C, 0.25W | TME România | 3.0573 | 0
54 | 50k | (LINK) (http://www.tme.eu/ro/details/3314g-1-503e/trimere-smd-cu-o-singura-tura/bourns/) | 3314G-1-503E | 3314G-1-503E | BOURNS | potențiometru | 0 |  | 0 | Potențiome-tru liniar, simplă tură, SMD, 50kΩ, ±20%, 100ppm/°C, 0.25W | TME România | 2.84 | 0
55 | 100k | (LINK) (http://www.tme.eu/ro/details/ts53yl100k/trimere-smd-cu-o-singura-tura/vishay/ts53yl104mr10/) | TS53YL104MR10 | TS53YL104MR10 | VISHAY | potențiometru | 0 |  | 0 | Potențiome-tru liniar, simplă tură, SMD, 100kΩ, ±20%, 100ppm/°C, 0.25W | TME România | 2.61 | 0
56 | 500k | (LINK) (http://www.tme.eu/ro/details/3314g-1-504e/trimere-smd-cu-o-singura-tura/bourns/) | 3314G-1-504E | 3314G-1-504E | BOURNS | potențiometru | 0 |  | 0 | Potențiome-tru liniar, simplă tură, SMD, 500kΩ, ±10%, 100ppm/°C, 0.25W | TME România | 2.8802 | 0
 | TOTAL - Componente pasive (rezistoare de valori fixe şi reglabile) |  |  |  |  |  |  |  |  | FARA TVA = | 265.8843 | CU TVA= | 329.696532
57 | 4.7pF | (LINK) (http://www.tme.eu/ro/details/cc0805crnpo94r7/condensatoare-mlcc-smd-0805/yageo/cc0805crnpo9bn4r7/) | CC0805CRNPO9BN4R7 | CC0805CRNPO9BN4R7 | YAGEO | condensator | 20 |  | 0 | ceramic; MLCC; 4,7pF; 50V; C0G; ±0,25pF; SMD; 0805 | TME România | 0.16643 | 3.3286
58 | 10pF | (LINK) (http://www.tme.eu/ro/details/cc0805jrnpo9100/condensatoare-mlcc-smd-0805/yageo/cc0805jrnpo9bn100/) | CC0805JRNPO9BN100 | CC0805JRNPO9BN100 | YAGEO | condensator | 20 |  | 0 | ceramic; MLCC; 10pF; 50V; C0G; ±5%; SMD; 0805 | TME România | 0.1649 | 3.298
59 | 47pF | (LINK) (http://www.tme.eu/ro/details/cl21c470jbannnc/condensatoare-mlcc-smd-0805/samsung/) | CL21C470JBANNNC | CL21C470JBANNNC | SAMSUNG | condensator | 20 |  | 0 | Condensator: ceramic; MLCC; 47pF; 50V; C0G; ±5%; SMD; 0805; -55÷125°C | TME România | 0.11097 | 2.2194
60 | 100pF | (LINK) (http://www.tme.eu/ro/details/cl21c101jbannnc/condensatoare-mlcc-smd-0805/samsung/) | CL21C101JBANNNC | CL21C101JBANNNC | SAMSUNG | condensator | 20 |  | 0 | Condensator: ceramic; MLCC; 100pF; 50V; C0G; ±5%; SMD; 0805 | TME România | 0.05427 | 1.0854
61 | 470pF | (LINK) (https://www.tme.eu/ro/details/cl21c471jbannnc/condensatoare-mlcc-smd-0805/samsung/) | CL21C471JBANNNC | CL21C471JBANNNC | SAMSUNG | condensator | 20 |  | 1 | Condensator: ceramic; MLCC; 470pF; 50V; X7R; ±10%; SMD; 0805 | TME România | 0.12123 | 2.4246
62 | 1nF | (LINK) (https://www.tme.eu/ro/details/cl21c102jbcnnnc/condensatoare-mlcc-smd-0805/samsung/) | CL21C102JBCNNNC | CL21C102JBCNNNC | SAMSUNG | condensator | 40 |  | 0 | Condensator MLCC, SMD, 0805, 1nF, ±5%, 50V, C0G | TME România | 0.06487 | 2.5948
63 | 2.2nF | (LINK) (https://www.tme.eu/ro/details/cl21b222jbannnc/condensatoare-mlcc-smd-0805/samsung/) | CL21B222JBANNNC | CL21B222JBANNNC | SAMSUNG | condensator | 0 |  | 0 | Condensator: ceramic; MLCC; 2,2nF; 50V; X7R; ±10%; SMD; 0805 | TME România | 0.1485 | 0
64 | 4.7nF | (LINK) (https://www.tme.eu/ro/details/cl21b472kbannnc/condensatoare-mlcc-smd-0805/samsung/) | CL21B472KBANNNC | CL21B472KBANNNC | SAMSUNG | condensator | 0 |  | 0 | Condensator MLCC, SMD, 0805, 4.7nF, ±5%, 50V, X7R | TME România | 0.08943 | 0
65 | 5.6nF | (LINK) (https://www.tme.eu/ro/details/cl21b562kbannnc/condensatoare-mlcc-smd-0805/samsung/) | CL21B562KBANNNC | CL21B562KBANNNC | SAMSUNG | condensator | 0 |  | 0 | Condensator MLCC, SMD, 0805, 5.6nF, ±5%, 50V, X7R | TME România | 0.04517 | 0
66 | 10nF | (LINK) (https://www.tme.eu/ro/details/cl21b103kbannnd/condensatoare-mlcc-smd-0805/samsung/) | CL21B103KBANNND | CL21B103KBANNND | SAMSUNG | condensator | 0 |  | 1 | Condensator MLCC, SMD, 0805, 10nF, ±5%, 50V, X7R | TME România | 0.06093 | 0
67 | 22nF | (LINK) (http://www.tme.eu/ro/details/cl21b223kcfnnne/condensatoare-mlcc-smd-0805/samsung/) | CL21B223KBANNNC | CL21B223KBANNNC | SAMSUNG | condensator | 0 |  | 0 | Condensator: ceramic; MLCC; 22nF; 100V; X7R; ±10%; SMD; 0805 | TME România | 0.13823 | 0
68 | 33nF | (LINK) (https://www.tme.eu/ro/details/vj0805y333kxacw1bc/condensatoare-mlcc-smd-0805/vishay/) | VJ0805Y333KXACW1BC | VJ0805Y333KXACW1BC | VISHAY | condensator | 0 |  | 0 | Condensator: ceramic; MLCC; 33nF; 50V; X7R; ±10%; SMD; 0805 | TME România | 0.05417 | 0
69 | 100nF | (LINK) (https://www.tme.eu/ro/details/cl21f104zbcnnnc/condensatoare-mlcc-smd-0805/samsung/) | CL21F104ZBCNNNC | CL21F104ZBCNNNC | SAMSUNG | condensator | 40 |  | 0 | ceramic; MLCC; 100nF; 50V; X7R; ±10%; SMD; 0805 | TME România | 0.3759 | 15.036
70 | 220nF | (LINK) (http://www.tme.eu/ro/details/cl21b224kafnnne/condensatoare-mlcc-smd-0805/samsung/) | CL21B224KAFNNNE | CL21B224KAFNNNE | SAMSUNG | condensator | 0 |  | 0 | Condensator: ceramic; MLCC; 220nF; 25V; X7R; ±10%; SMD; 0805 | TME România | 0.10247 | 0
71 | 330nF | (LINK) (https://www.tme.eu/ro/details/grm219r71h334ka88d/condensatoare-mlcc-smd-0805/murata/) | GRM219R71H334KA88D | GRM219R71H334KA88D | MURATA | condensator | 0 |  | 0 | Condensator: ceramic; MLCC; 330nF; 50V; X7R; ±10%; SMD; 0805 | TME România | 0.5972 | 0
72 | 470nF | (LINK) (https://www.tme.eu/ro/details/cc0805mry5v8474/condensatoare-mlcc-smd-0805/yageo/cc0805mry5v8bb474/) | CC0805MRY5V8474 | CC0805MRY5V8BB474 | YAGEO | condensator | 0 |  | 0 | Condensator: ceramic; MLCC; 470nF; 50V; Y5V; -20÷+80%; SMD; 0805 | TME România | 0.0758 | 0
73 | 1uF | (LINK) (https://www.tme.eu/ro/details/cl21b105kbfnnng/condensatoare-mlcc-smd-0805/samsung/) | CL21B105KBFNNNG | CL21B105KBFNNNG | SAMSUNG | condensator | 20 |  | 0 | Condensator: ceramic; MLCC; 1uF; 50V; X7R; ±20%; SMD; 0805 | TME România | 0.25253 | 5.0506
74 | 2.2uF | (LINK) (https://www.tme.eu/ro/details/grm21br61h225ka73l/condensatoare-mlcc-smd-0805/murata/) | GRM21BR61H225KA73L | GRM21BR61H225KA73L | MURATA | condensator | 20 |  | 0 | Condensator: ceramic; MLCC; 2,2uF; 25V; X5R; ±10%; SMD; 0805 | TME România | 0.4486 | 8.972
75 | 4.7uF | (LINK) (https://www.tme.eu/ro/details/cl21a475kaqnnng/condensatoare-mlcc-smd-0805/samsung/) | CL21A475KAQNNNG | CL21A475KAQNNNG | SAMSUNG | condensator | 20 |  | 0 | ceramic; MLCC; 4,7uF; 25V; X5R; ±10%; SMD; 0805 | TME România | 0.25373 | 5.0746
76 | 10uF | (LINK) (https://www.tme.eu/ro/details/ce10_50-smd/condensatoare-electrolitice-smd-85c/) | CE10/50-SMD | CE10/50-SMD | TME | condensator | 16 |  | 0 | Condensator: electrolitic; SMD; 10uF; 50V | TME România | 0.2284 | 3.6544
 | TOTAL - Componente pasive (condensatoare) |  |  |  |  |  |  |  |  | FARA TVA = | 52.7384 | CU TVA= | 65.395616
77 | 4148 | (LINK) (http://www.tme.eu/ro/details/1n4148-0805/diode-universale-smd/dc-components/cd4148ws0805c/) | 1N4148-0805 | CD4148WS(0805C) | DC Components | diodă pn | 40 |  | 4 | Diodă comutație, SMD, 0805, 300mA, 100V | TME România | 0.04555 | 1.822
78 | LED | (LINK) (https://www.tme.eu/ro/details/of-smd2012b/diode-led-smd-colorate/optoflash/) | OF-SMD2012B | OF-SMD2012B | OPTOFLASH | LED | 15 |  | 2 | LED albastru, SMD, 0805, 150-200mcd, 476nm, 120° | TME România | 0.1264 | 1.896
79 | 2.7V | (LINK) (http://www.tme.eu/ro/details/bzx84c2v7/diode-zener-smd/on-semiconductor/bzx84c2v7lt1g/) | BZX84C2V7 | BZX84-C2V7LT1G | ON Semiconductor | diodă Zener | 0 |  | 0 | Diodă Zener, SMD, SOT23, 2,7V, ±5%, 0.25W | TME România | 0.05732 | 0
80 | 5.1V | (LINK) (https://www.tme.eu/ro/details/bzx84-c5v1.215/diode-zener-smd/nexperia/) | BZX84C5V1 | BZX84-C5V1 | NEXPERIA | diodă Zener | 10 |  | 0 | Diodă Zener, SMD, SOT23, 5,1V, ±5%, 0.3W | TME România | 0.06245 | 0.6245
81 | 5.6V | (LINK) (https://www.tme.eu/ro/details/bzx84b5v6-dio/diode-zener-smd/diotec-semiconductor/bzx84b5v6/) | BZX84B5V6 | BZX84B5V6 | DIOTEC SEMICONDUCTOR | diodă Zener | 10 |  | 0 | Diodă Zener, SMD, SOT23, 5,6V, ±5%, 0.3W | TME România | 0.0839 | 0.839
82 | 6.2V | (LINK) (https://www.tme.eu/ro/details/bzx84-c6v2.215/diode-zener-smd/nexperia/) | BZX84C6V2 | BZX84-C6V2 | NEXPERIA | diodă Zener | 0 |  | 0 | Diodă Zener, SMD, SOT23, 6.2V, ±5%, 0.3W | TME România | 0.06618 | 0
83 | 6.8V | (LINK) (https://www.tme.eu/ro/details/bzx84-c6v8.215/diode-zener-smd/nexperia/) | BZX84C6V8 | BZX84-C6V8 | NEXPERIA | diodă Zener | 0 |  | 0 | Diodă Zener, SMD, SOT23, 6.8V, ±5%, 0.3W | TME România | 0.05686 | 0
84 | 8.2V | (LINK) (https://www.tme.eu/ro/details/bzx84-c8v2.215/diode-zener-smd/nexperia/) | BZX84C8V2 | BZX84-C8V2 | NEXPERIA | diodă Zener | 0 |  | 0 | Diodă Zener, SMD, SOT23, 8.2V, ±5%, 0.3W | TME România | 0.05686 | 0
85 | 10V | (LINK) (https://www.tme.eu/ro/details/bzx84-c10.215/diode-zener-smd/nexperia/) | BZX84C10 | BZX84-C10 | NEXPERIA | diodă Zener | 0 |  | 0 | Diodă Zener, SMD, SOT23, 10V, ±5%, 0.3W | TME România | 0.05686 | 0
86 | PNP | (LINK) (http://www.tme.eu/ro/details/bc856b-dio/tranzistori-smd-pnp/diotec-semiconductor/bc856b/) | BC856B | BC856B | DIOTEC | tranzistor bipolar | 120 |  | 6 | Tranzistor bipolar PNP, SMD, SOT23, 80V, 100mA | TME România | 0.04055 | 4.866
87 | NPN | (LINK) (https://www.tme.eu/ro/details/bc846b-dio/tranzistori-smd-npn/diotec-semiconductor/bc846b/) | BC846B | BC846B | DIOTEC | tranzistor bipolar | 120 |  | 5 | Tranzistor bipolar NPN, SMD, SOT23, 65V, 100mA | TME România | 0.03379 | 4.0548
89 | N-JFET | (LINK) (http://www.tme.eu/ro/details/mmbfj309lt1g/tranzistori-canal-n-smd/on-semiconductor/) | MMBFJ309LT1G | MMBFJ309LT1G | ON Semiconductor | tranzistor NJFET | 40 |  | 0 | Tranzistor N-JFET, SMD, SOT23, 25V, 30mA | TME România | 0.8063 | 32.252
90 | P-JFET | (LINK) (http://www.tme.eu/ro/details/mmbfj177lt1g/tranzistori-canal-p-smd/on-semiconductor/) | MMBFJ177LT1G | MMBFJ177LT1G | ON Semiconductor | tranzistor PJFET | 0 |  | 0 | Tranzistor P-JFET, SMD, SOT23, 30V, 20mA | TME România | 0.8808 | 0
91 | NPN | (LINK) (http://www.tme.eu/ro/details/bc817-25-dio/tranzistori-smd-npn/diotec-semiconductor/bc817-25/) | BC817-25-DIO | BC817-25-DIO | NXP | tranzistor bipolar | 20 |  | 0 | Tranzistor bipolar NPN, SMD, SOT23, 45V, 800mA | TME România | 0.0494 | 0.988
93 | PNP | (LINK) (http://www.tme.eu/ro/details/bc807-25-dio/tranzistori-smd-pnp/diotec-semiconductor/bc807-25/) | BC807-25-DIO | BC807-25-DIO | NXP | tranzistor bipolar | 20 |  | 0 | Tranzistor bipolar PNP, SMD, SOT23, 45V, 800mA | TME România | 0.05406 | 1.0812
94 | NPN | (LINK) (http://www.tme.eu/ro/details/mjd31cg/tranzistori-smd-npn/on-semiconductor/) | MJD31CG | MJD31CG | ON Semiconductor | tranzistor bipolar | 0 |  | 0 | Tranzistor bipolar NPN, SMD, DPACK, 100V, 3A, 15W | TME România | 0.7037 | 0
96 | PNP | (LINK) (http://www.tme.eu/ro/details/mjd32cg/tranzistori-smd-pnp/on-semiconductor/) | MJD32CG | MJD32CG | ON Semiconductor | tranzistor bipolar | 0 |  | 0 | Tranzistor bipolar PNP, SMD, DPACK, 100V, 3A, 15W | TME România | 0.783 | 0
97 | Nmos | (LINK) (http://www.tme.eu/ro/details/irfr120npbf/tranzistori-canal-n-smd/international-rectifier/) | IRFR120NPBF | IRFR120NPBF | International Rectifier | tranzistor NMOS | 0 |  | 0 | Tranzistor N-MOSFET, SMD, DPAK, 100V, 9.1A, 20V, 39W | TME România | 1.03 | 0
 | TOTAL - Componente semiconductoare (tranzistoare bipolare şi cu efect de câmp, diode, LED, etc.) |  |  |  |  |  |  |  |  | FARA TVA = | 75.7235 | CU TVA= | 93.89714
98 | Conn2p | (LINK) (http://www.tme.eu/ro/details/zl301-40p/pini-cu-benzi-si-soclu/ninigi/) | ZL301-40P | ZL301-40P | NINIGI | Sir pini, pas 2,54mm, SMD | 0 |  | 0 | Sir pini, pas 2,54mm, SMD, tip tata, bareta de 40 pini | TME România | 2.3027 | 0
99 | FUSE | (LINK) (http://www.tme.eu/ro/details/3413.0116.11/sigurante-smd-1206-ultrarapide/schurter/) | 3413.0116.11 | 3413.0116.11 | SCHURTER | sigu-ranță | 0 |  | 0 | Siguranță sticlă, SMD, 1206, 1.25A, 48mΩ | TME România | 0 | 0
 | Total - Conectică, sigurante fuzibile, etc. |  |  |  |  |  |  |  |  | FARA TVA = | 0 | CU TVA= | 0
 | Total general |  |  |  |  |  |  |  |  | FARA TVA = | 394.3462 | CU TVA= | 469.271978

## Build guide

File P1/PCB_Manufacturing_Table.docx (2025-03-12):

General info document for PCB manufacturing
No. | Item Name | File Name | | | | | | Info / Remarks / Notes
| BOARD
1 | Board Name / Number | SHEMA 2.7 .brd | | | | | | -
2 | Revision Date | 15 December 2024 | | | | | | -
3 | Board Size | 40 x 40 mm² | | | | | | -
4 | Board Quantity | 1 | | | | | | -
5 | Material / Dielectric Type | FR-4 | | | | | | -
6 | Board Thickness | 1.6 mm | | | | | | -
7 | Copper Thickness | 18 μm | | | | | | -
| LAYERS
8 | Number of Electrical Layers | 2 | | | | | | -
9 | Copper Layer TOP | TOP.art | | | | | | -
10 | Copper Layer BOTTOM | BOTTOM.art | | | | | | -
11 | Copper GND Plane | - | | | | | | -
12 | Copper PWR Plane | - | | | | | | -
13 | Copper INNER 1 | - | | | | | | -
14 | Copper INNER 2 | - | | | | | | -
15 | Solder Mask TOP | SMTOP.art | | | | | | -
16 | Solder Mask BOTTOM | SMBOT.art | | | | | | -
17 | Solder Paste TOP | SPTOP.art | | | | | | -
18 | Solder Paste BOTTOM | - | | | | | | -
19 | Peelable Mask TOP | - | | | | | | -
20 | Peelable Mask BOTTOM | - | | | | | | -
21 | Silk Screen TOP | SSTOP.art | | | | | | -
22 | Silk Screen BOTTOM | - | | | | | | -
23 | Board Outline | BO.art | | | | | | -
24 | Fabrication Drawing | FAB.art | | | | | | -
| MILLING & DRILLING
25 | Mill Drawing | - | | | | | | -
26 | Drill Drawing | - | | | | | | -
27 | N.C. Drill (for both PH & NPH) | - | | | | | | -
28 | N.C. Drill / Plated Holes (PH) | DRILL.drl | | | | | | -
29 | N.C. Drill / Non-Plated Holes (PH) | - | | | | | | -
| FINISHING
30 | Panelisation | - | | | | | | -
31 | Electrical Test | - | | | | | | -
32 | Copper Finishing | x | HASL | | OSP | | | ENIG
33 | Board Outline Machining | | Routing | | Milling | | x | V-Cutting
34 | Final remarks | - | | | | -
